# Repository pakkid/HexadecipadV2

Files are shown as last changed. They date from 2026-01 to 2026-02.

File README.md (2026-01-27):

# HexadecipadV2

A fully customizable macro pad with 24 mechanical switches and 4 rotary encoders, designed with KiCAD and featuring an little baby RP2040 microcontroller.

## Overview

HexadecipadV2 is hackpad designed for the blueprint/hackpad ysws. I spent about 6 hours pulling my hair out over case design before I knew what I was doing... ps. I still have no idea what I'm doing.

**Key Features:**
- 24 hot-swap MX-compatible mechanical switches (oops)
- 4 rotary encoders for volume control, scrolling, or custom functions (more oops)
- Seeed Studio XIAO RP2040 microcontroller
- MCP23017 I/O expander because XIAO RP2040 is little baby.
- Open-source KiCAD design because i broke.
- 3D-printed case 👍
- Too many inputs. checked with Blueprint Support, they said its fine as long as I pay.
- Too big pcb (100mmx130mm) also checked with Blueprint staff.
- Fully custom vibe coded garbage script that send serial to a python script on my pc so we can modify keys without having to use stupid kmk.

## Project Structure (just the READMEs for when you access on github.io)

```
HexadecipadV2/
├── CAD/                     # Case and mechanical design files
│   └── README.md            # CAD file documentation
├── Firmware/                # Source firmware code
│   └── README.md            # Firmware documentation
├── PCB/                     # KiCad PCB design files
│   └── HexadecipadV2/       # Main PCB project
│       └── README.md        # PCB documentation
├── Production/              # Manufacturing-ready files
│   ├── CAD/                 # STL files for 3D printing
│   │   └── README.md        # 3D printing guide
│   ├── Firmware/            # Production firmware
│   │   └── README.md        # Firmware installation guide
│   ├── PCB/                 # Gerber files for PCB fab
│   │   └── README.md        # PCB ordering guide
│   └── README.md            # Production overview
└── Other files/             # Supporting files
    ├── 3d models/           # Component STEP models
    │   └── README.md        # 3D models documentation
    ├── images/              # Documentation images
    │   └── README.md        # Images documentation
    └── README.md            # Other files overview
```

### Links and stuff
- **[CAD Files](CAD/)** - Case design and mechanical files
- **[Firmware](Firmware/)** - Source code and development files
- **[PCB Design](PCB/)** - KiCad project and design files
- **[Production Files](Production/)** - Ready-to-manufacture files
  - [3D Printable Case Files](Production/CAD/)
  - [Production Firmware](Production/Firmware/)
  - [PCB Manufacturing Files](Production/PCB/)
- **[Other Files](Other%20files/)** - Component models and documentation images
 
## Screenshots

### Hackpad

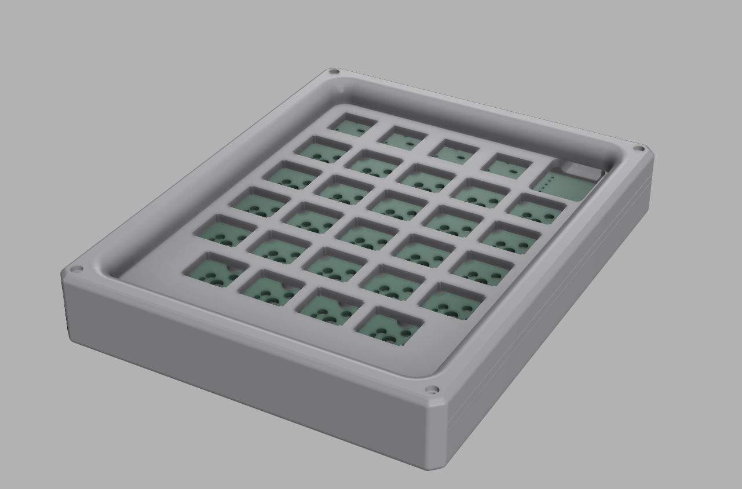
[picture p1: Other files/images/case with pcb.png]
Hackpad Overview


### Schematic

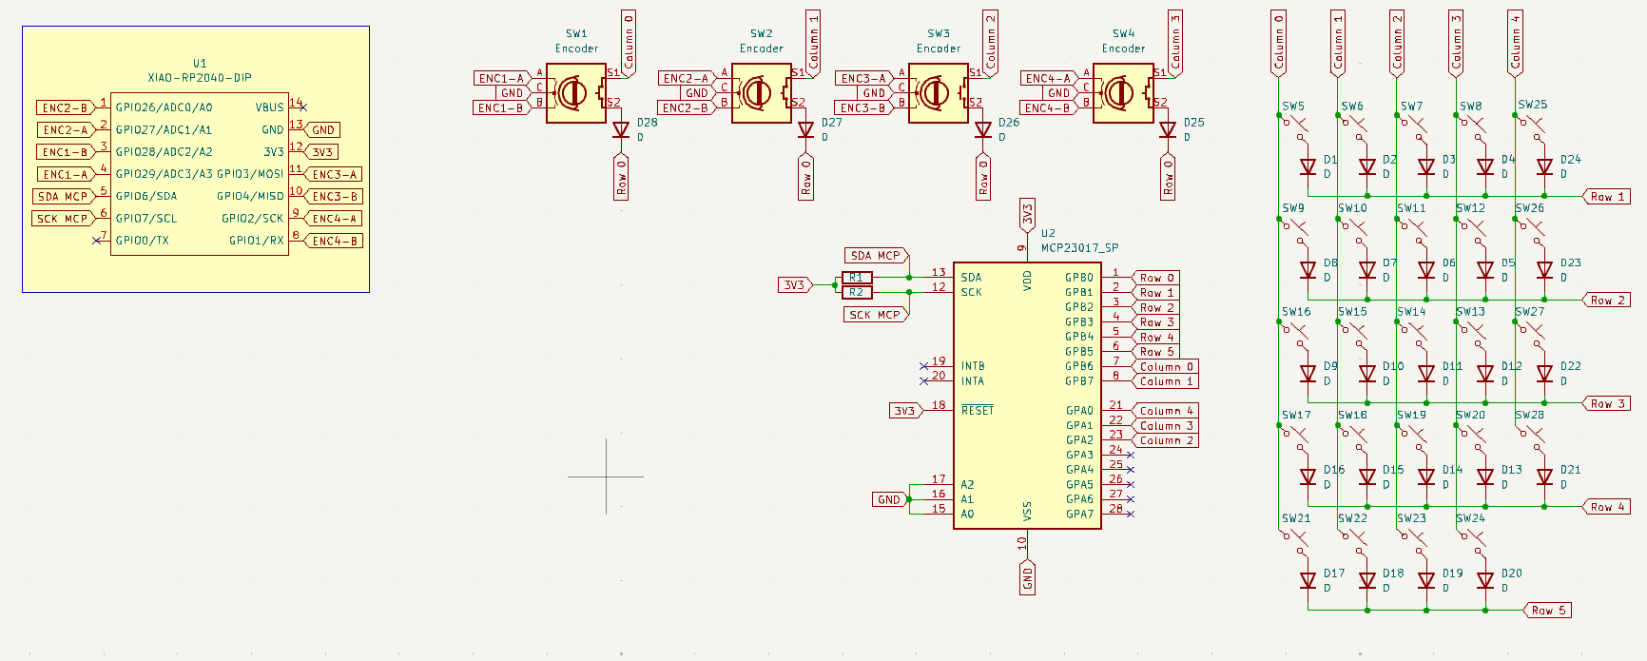
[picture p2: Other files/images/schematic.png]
Schematic


### PCB

**PCB Filled:**
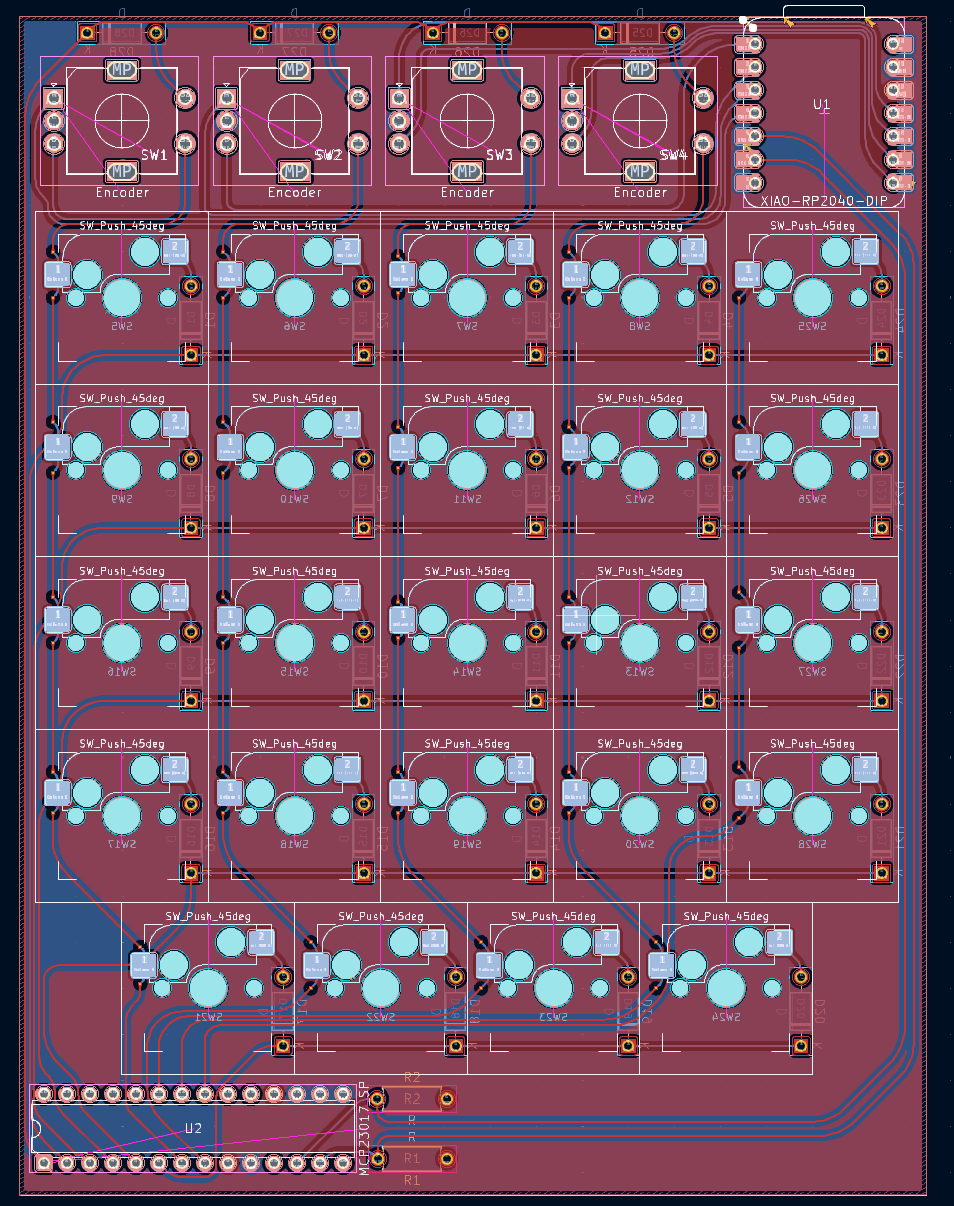
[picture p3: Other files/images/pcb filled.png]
PCB Filled


**PCB Unfilled:**
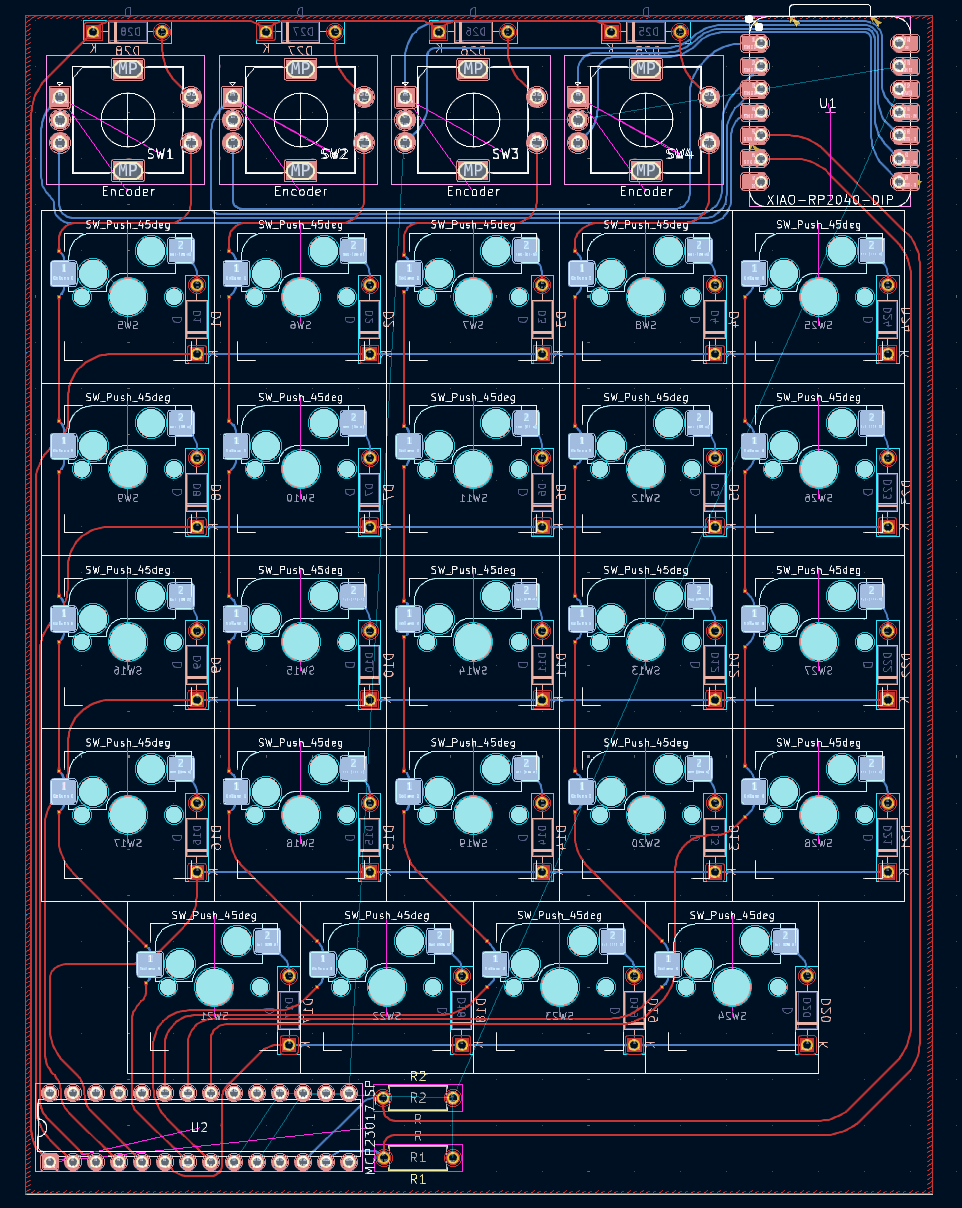
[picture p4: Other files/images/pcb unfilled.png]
PCB Unfilled


### Case Assembly

Case Assembly

## Bill of Materials (BOM)

| # | References | Value | Footprint | Quantity |
|---|---|---|---|---|
| 1 | R1, R2 | R | R_Axial_DIN0207_L6.3mm_D2.5mm_P7.62mm_Horizontal | 2 |
| 2 | D1–D28 | D | D_DO-35_SOD27_P7.62mm_Horizontal | 28 |
| 3 | U1 | XIAO-RP2040-DIP | XIAO-RP2040-DIP | 1 |
| 4 | U2 | MCP23017_SP | DIP-28_W7.62mm | 1 |
| 5 | SW5–SW28 | SW_Push_45deg | MX-Hotswap-1U | 24 |
| 6 | SW1–SW4 | Encoder | RotaryEncoder_Alps_EC11E-Switch_Vertical_H20mm | 4 |
| 7 | N/A | M3x16mm screws | N/A | 4 |

 - **[Interactive BOM](https://hxdcpd.stuffandthings.cc/PCB/HexadecipadV2/bom/ibom.html)**

## Design Files

- **Schematic:** [PCB/HexadecipadV2/HexadecipadV2.kicad_sch](PCB/HexadecipadV2/HexadecipadV2.kicad_sch)
- **PCB Layout:** [PCB/HexadecipadV2/HexadecipadV2.kicad_pcb](PCB/HexadecipadV2/HexadecipadV2.kicad_pcb)
- **PCB 3D Model:** [PCB/HexadecipadV2/HexadecipadV2.step](PCB/HexadecipadV2/HexadecipadV2.step)
- **Case Design:** [CAD/HexadecipadV2-assembled.step](CAD/HexadecipadV2-assembled.step)

### Firmware

Have a look at [Firmware](Firmware/) to see my stupid code.

## License

This project is licensed under the MIT License - see the [LICENSE](LICENSE) file for details.

## Contributing

Contributing will probably end up with me being fried because of my terrible everything in this project.

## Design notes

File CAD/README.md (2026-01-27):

# CAD Directory

This directory contains all Computer-Aided Design (CAD) files for the HexadecipadV2 case and mechanical design.

## Files

### Case Design Files

- **Case-Production.shapr** - Shapr3D native file format for the case design (editable source file)
- **Case.step** - STEP format export of the case design for universal CAD compatibility
- **Case.x_t** - Parasolid format export of the case design
- **HexadecipadV2-assembled.step** - Complete assembled model in STEP format showing the full device assembly
- **platecutout.dxf** - DXF file for the switch plate cutout pattern, used for laser cutting or CNC machining

## File Formats

- `.shapr` - Shapr3D native format (requires Shapr3D software)
- `.step` / `.stp` - Industry-standard 3D CAD format, compatible with most CAD software
- `.x_t` - Parasolid format, widely supported in professional CAD applications
- `.dxf` - 2D drawing exchange format for manufacturing processes

## Usage

The production-ready files for manufacturing are:
- `platecutout.dxf` for the switch plate
- `Case.step` or `Case.x_t` for the case (depending on your manufacturer's preference)

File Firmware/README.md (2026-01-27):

# Firmware Directory

This directory contains the source firmware code for the HexadecipadV2.

## Files

- **main.py** - Main entry point for the CircuitPython firmware
- **hexadecipad_control.py** - Control logic and functionality for the Hexadecipad (key handling, LED control, etc.)

## Hardware Requirements

This firmware is designed for:
- Seeed Studio XIAO RP2040 microcontroller
- CircuitPython 10.0.3 or compatible version

For production-ready firmware files, see the `/Production/Firmware/` directory.

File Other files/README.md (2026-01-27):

# Other Files Directory

This directory contains supporting files including 3D models and documentation images.

## Subdirectories

### 3d models/
Contains 3D STEP models of components used in the design:
- **asm_mx_asm_PCB.stp** - MX mechanical switch assembly with PCB
- **Encoder.STEP** - Rotary encoder 3D model
- **Seeed Studio XIAO RP2040 v26.step** - 3D model of the XIAO RP2040 microcontroller

### images/
Contains project documentation images:
- **case with pcb.png** - Render showing the PCB mounted in the case
- **pcb filled.png** - PCB view with filled copper zones visible
- **pcb unfilled.png** - PCB view without filled zones
- **schematic.png** - Electronic schematic diagram

## Usage

These files are primarily used for:
- 3D models: CAD visualization and mechanical clearance verification
- Images: README documentation and project showcase

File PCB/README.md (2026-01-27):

# PCB Directory

This directory contains the printed circuit board (PCB) design files for HexadecipadV2.

## Subdirectories

### HexadecipadV2/
Main PCB design directory containing all KiCad project files:

#### Project Files
- **HexadecipadV2.kicad_pro** - KiCad project file
- **HexadecipadV2.kicad_sch** - KiCad schematic file
- **HexadecipadV2.kicad_pcb** - KiCad PCB layout file
- **HexadecipadV2.kicad_prl** - KiCad project local settings
- **HexadecipadV2.step** - 3D model export of the PCB

#### Configuration Files
- **fp-lib-table** - Footprint library table
- **sym-lib-table** - Symbol library table
- **fp-info-cache** - Footprint information cache

#### Subdirectories
- **3d models/** - Component 3D models for PCB visualization
- **bom/** - Bill of Materials files (includes `ibom.html` - Interactive HTML BOM)
- **libraries/** - Custom KiCad libraries including footprints and symbols
  - `Hackpad/` - Custom Hackpad symbols and footprints
  - `kicad-keyboard-parts.pretty-master/` - Keyboard-specific footprints
  - `MX_V2-main/` - MX switch footprint library
  - `OPL_Kicad_Library-master/` - Open Parts Library
  - `RotaryEncoder/` - Rotary encoder components
- **HexadecipadV2-backups/** - Automatic KiCad backup files

## Software Requirements

- KiCad 7.0 or later (recommended for full compatibility)

## Usage

1. Open `HexadecipadV2.kicad_pro` in KiCad to view and edit the design
2. Use `ibom.html` in the `bom/` folder for assembly reference
3. For manufacturing files, see the `/Production/PCB/` directory

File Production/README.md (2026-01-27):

# Production Directory

This directory contains production-ready files for manufacturing and assembly of the HexadecipadV2.

## Subdirectories

### CAD/
3D printable STL files for case manufacturing:
- **Case bottom.stl** - Bottom half of the case
- **Case top.stl** - Top half of the case
- **Plate.stl** - Switch mounting plate

### Firmware/
Production firmware ready for deployment:
- **adafruit-circuitpython-seeeduino_xiao_rp2040-en_US-10.0.3.uf2** - CircuitPython bootloader/runtime for XIAO RP2040
- **CIRCUITPY/** - Directory structure to be copied to the device
  - `main.py` - Production firmware main file
  - `lib/` - Required CircuitPython libraries

### PCB/
Manufacturing files for PCB fabrication:
- **Hexadecipad_V2_TDSOTM_Edition.zip** - Complete Gerber files and manufacturing package for PCB production
- **netlist.ipc** - IPC-356 netlist for PCB testing and verification

## Manufacturing Instructions

### PCB
1. Send `Hexadecipad_V2_TDSOTM_Edition.zip` to your PCB manufacturer
2. Recommended specs: Check the PCB.md file in /PCB/HexadecipadV2/

### Case
1. 3D print the STL files in the CAD/ directory
2. Recommended settings: 0.2mm layer height, 20% infill or higher
3. Material: PLA, ABS, or really whatever you want

### Firmware Installation
1. Flash `adafruit-circuitpython-seeeduino_xiao_rp2040-en_US-10.0.3.uf2` to the XIAO RP2040 by entering bootloader mode
2. Copy contents of `CIRCUITPY/` to the mounted CIRCUITPY drive
3. Device will automatically restart with the firmware

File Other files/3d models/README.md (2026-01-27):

# 3D Models

This directory contains STEP files of electronic components used in the HexadecipadV2 design.

## Files

- **asm_mx_asm_PCB.stp** - Complete assembly model of MX mechanical keyboard switch with PCB mounting
- **Encoder.STEP** - 3D model of the rotary encoder component
- **Seeed Studio XIAO RP2040 v26.step** - 3D model of the Seeed Studio XIAO RP2040 microcontroller board (version 26)

## Usage

These STEP models are used for:
- Verifying mechanical clearances in CAD assemblies
- Creating accurate renders and visualizations
- Checking component fit and interference
- PCB 3D visualization in KiCad

These files can be imported into most CAD software packages including KiCad, Fusion 360, SolidWorks, and FreeCAD.

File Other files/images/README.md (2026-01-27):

# Images

This directory contains documentation and visualization images for the HexadecipadV2 project.

## Files

- **case with pcb.png** - 3D render showing the PCB installed in the case assembly
- **pcb filled.png** - PCB layout view with filled copper zones (ground and power planes visible)
- **pcb unfilled.png** - PCB layout view with unfilled zones (traces and routing more visible)
- **schematic.png** - Complete electronic schematic diagram of the circuit

## Usage

These images are used in:
- Project README and documentation
- Assembly guides
- Design reviews
- Showcasing the project

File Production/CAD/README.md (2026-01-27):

# Production CAD Files

This directory contains production-ready STL files for 3D printing the HexadecipadV2 case.

## Files

- **Case bottom.stl** - Bottom housing of the case
- **Case top.stl** - Top housing/cover of the case
- **Plate.stl** - Switch mounting plate (goes between top and bottom)

## 3D Printing Recommendations

### Settings
- **Layer Height:** 0.2mm (or 0.15mm for better surface finish)
- **Infill:** 20% or higher
- **Wall Thickness:** 3-4 perimeters
- **Top/Bottom Layers:** 4-5 layers

### Print Orientation
Orient parts to minimize supports and maximize strength. The plate should be printed flat for dimensional accuracy.

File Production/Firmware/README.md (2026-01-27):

# Production Firmware

This directory contains production-ready firmware files for the HexadecipadV2.

## Files

- **adafruit-circuitpython-seeeduino_xiao_rp2040-en_US-10.0.3.uf2** - CircuitPython 10.0.3 firmware for the Seeed Studio XIAO RP2040

### CIRCUITPY/
Directory structure to be copied to the device after CircuitPython installation:
- **main.py** - Main firmware application
- **lib/** - Required CircuitPython libraries and dependencies

## Installation Instructions

### Step 1: Install CircuitPython Bootloader
1. Connect your XIAO RP2040 to your computer via USB
2. Press the RESET button twice quickly to enter bootloader mode
3. A drive named "RPI-RP2" should appear
4. Copy `adafruit-circuitpython-seeeduino_xiao_rp2040-en_US-10.0.3.uf2` to the RPI-RP2 drive
5. The device will automatically reboot and appear as "CIRCUITPY"

### Step 2: Install Firmware
1. Copy the entire contents of the `CIRCUITPY/` folder to the CIRCUITPY drive
2. Ensure `main.py` is in the root of the CIRCUITPY drive
3. Copy the `lib/` folder and its contents to the CIRCUITPY drive
4. The device will automatically restart and run the firmware

## Troubleshooting

- If the device doesn't appear as CIRCUITPY after step 1, try pressing RESET twice again
- If there are errors, check the `serial console` for error messages
- Ensure all required libraries are present in the `lib/` folder

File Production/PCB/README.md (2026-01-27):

# Production PCB Files

This directory contains manufacturing files for PCB fabrication.

## Files

- **Hexadecipad_V2_TDSOTM_Edition.zip** - Gerbers and drill files

- **netlist.ipc** - IPC-356 netlist file for electrical testing and verification of the manufactured PCB

## Ordering PCBs

### Upload Files
1. Upload `Hexadecipad_V2_TDSOTM_Edition.zip` to your PCB manufacturer (JLCPCB, PCBWay, OSH Park, etc.)

### Recommended Specifications
- Check the main PCB.md file in `/PCB/HexadecipadV2/` for detailed specifications
- Common settings:
  - **Layers:** 2
  - **PCB Thickness:** 1.6mm (standard)
  - **Surface Finish:** HASL or ENIG
  - **Copper Weight:** 1oz (35μm)

### Assembly
- For hand assembly, use the interactive BOM in `/PCB/HexadecipadV2/bom/ibom.html`
- For automated assembly, the pick-and-place files are included in the ZIP

## Quality Control

The `netlist.ipc` file can be used by the manufacturer or for in-house testing to verify:
- All connections are correct
- No short circuits exist
- All nets are properly connected

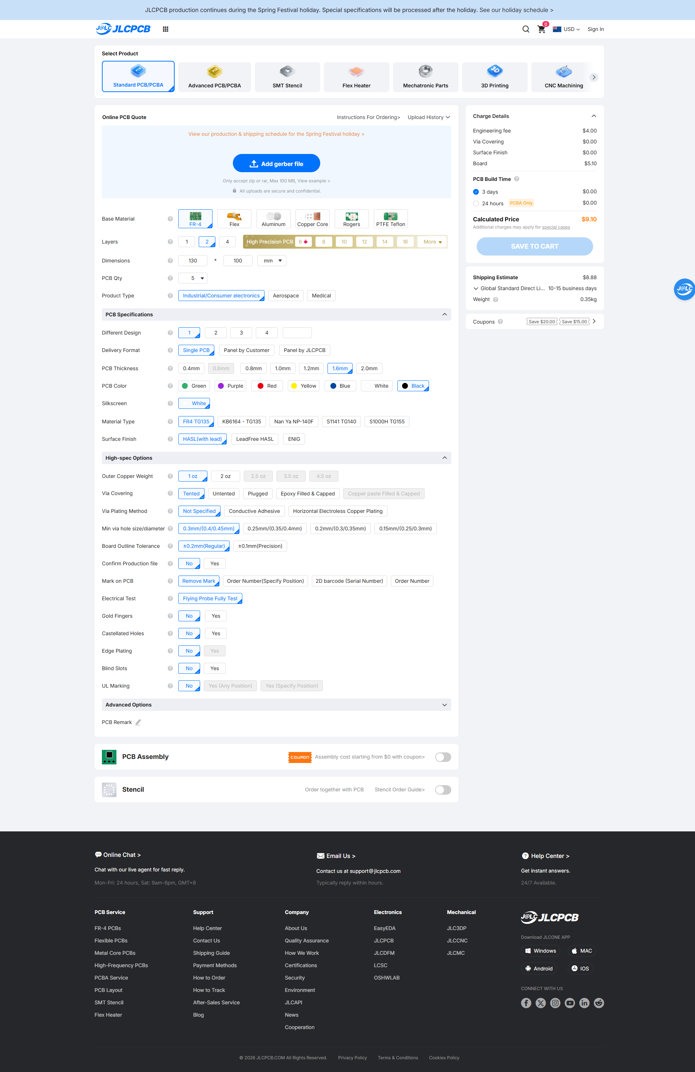
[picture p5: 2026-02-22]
PCB/screenshots-jlcpcb/130x100.png

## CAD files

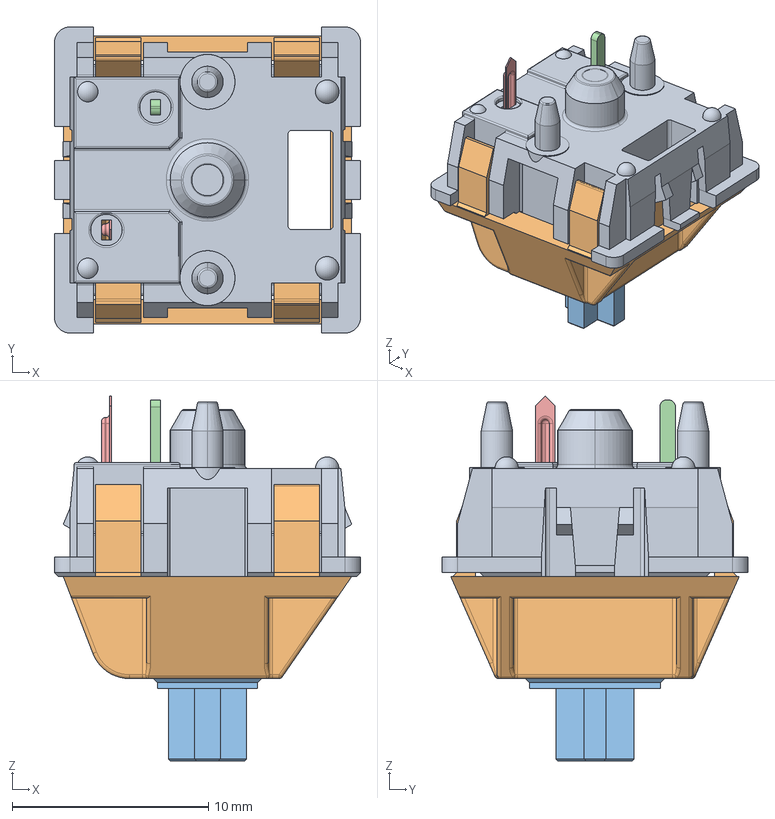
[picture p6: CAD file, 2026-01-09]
Other files/3d models/asm_mx_asm_PCB.stp
15.6 x 15.6 x 18.6 mm
MX_DOWN
MX_UP
UP_MX
MX_PIN
MX_SPRING
MX_CLICK

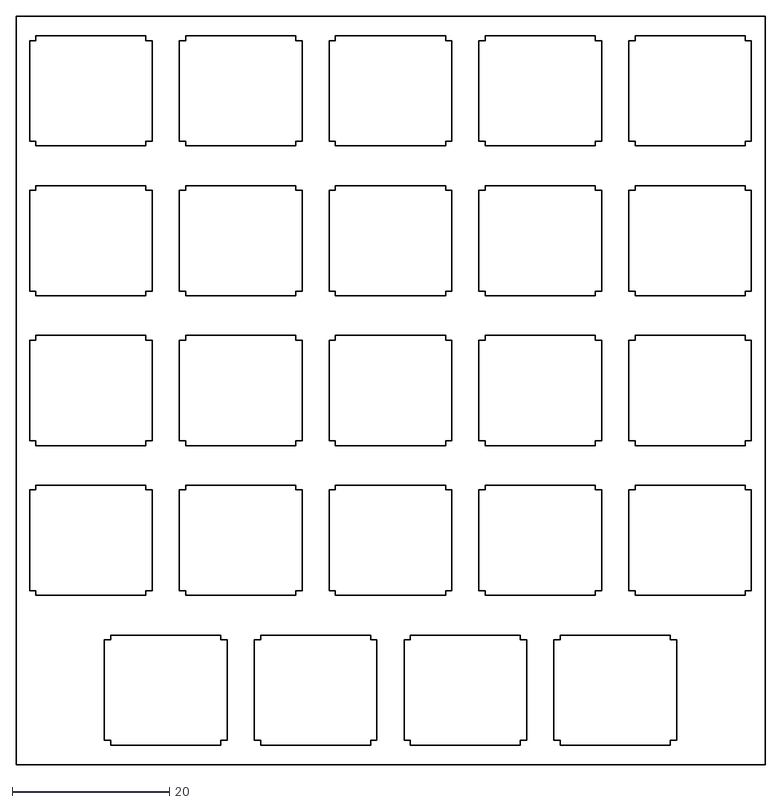
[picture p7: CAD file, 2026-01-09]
CAD/platecutout.dxf
95.3 x 95.2

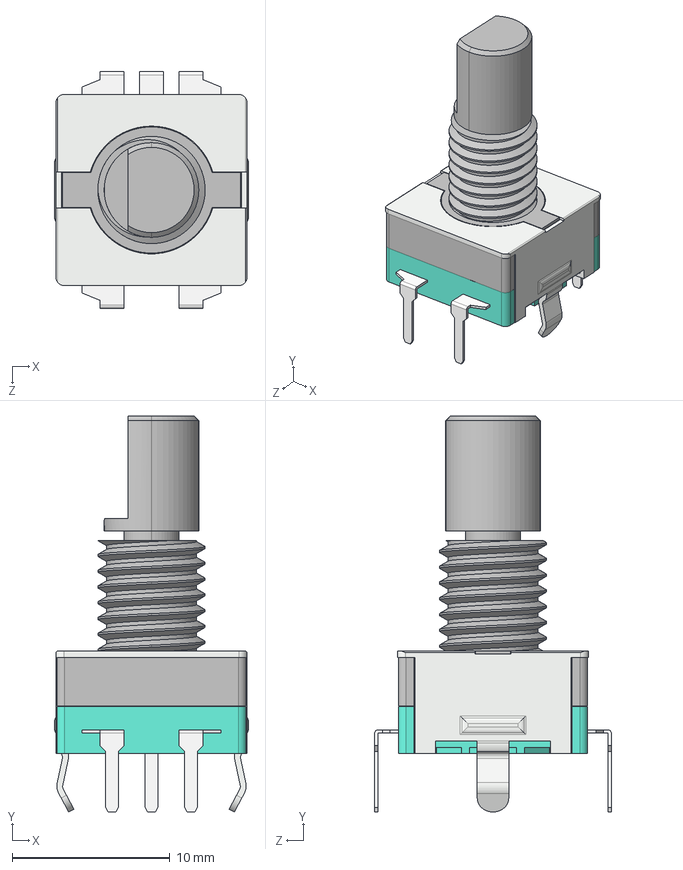
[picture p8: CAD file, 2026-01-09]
Other files/3d models/Encoder.STEP
12.3 x 25.1 x 15.0 mm

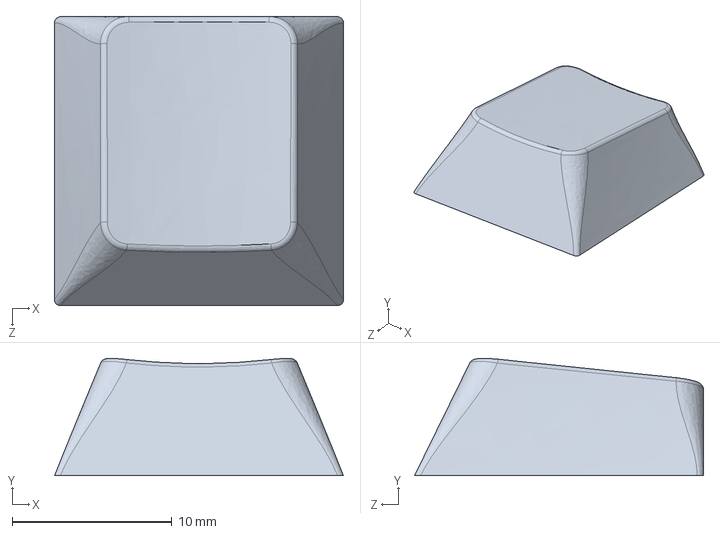
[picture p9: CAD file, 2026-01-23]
PCB/HexadecipadV2/3d models/r3_100.STEP
18.1 x 7.34 x 18.1 mm

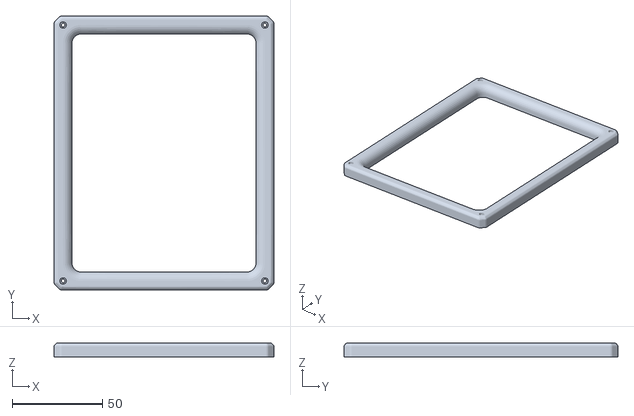
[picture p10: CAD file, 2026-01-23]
Production/CAD/Case top.stl
122.0 x 152.0 x 8.00

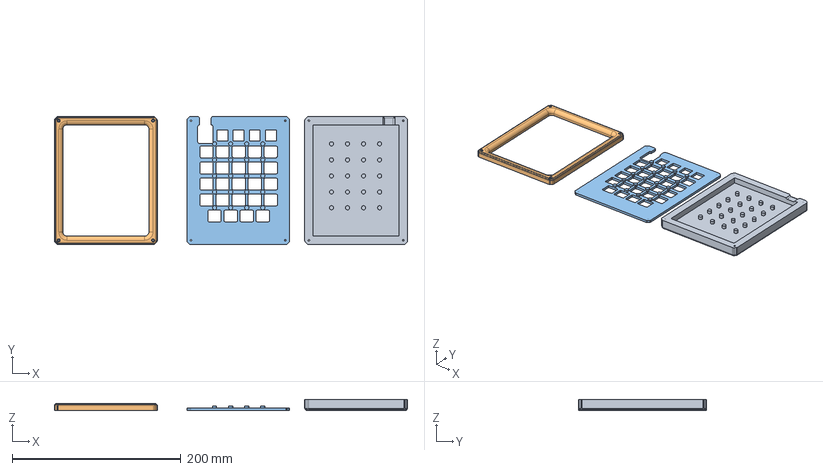
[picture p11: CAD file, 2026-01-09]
CAD/Case.step
419.0 x 152.0 x 12.6 mm
MX_DOWN
MX_UP
UP_MX
MX_PIN
MX_SPRING
MX_CLICK
type-c v2:1
smd_button v3:1
DOUT:1
DIN:1
VSS:1
VDD:1
smd_button v3(Mirror):1
Encoder x 4
DIP-28_W7.62mm
R_Axial_DIN0207_L6.3mm_D2.5mm_P7.62mm_Horizontal x 2
MX-Hotswap-Socket x 24
D_DO-35_SOD27_P7.62mm_Horizontal x 28
HexadecipadV2_silkscreen
HexadecipadV2_PCB
temp_import

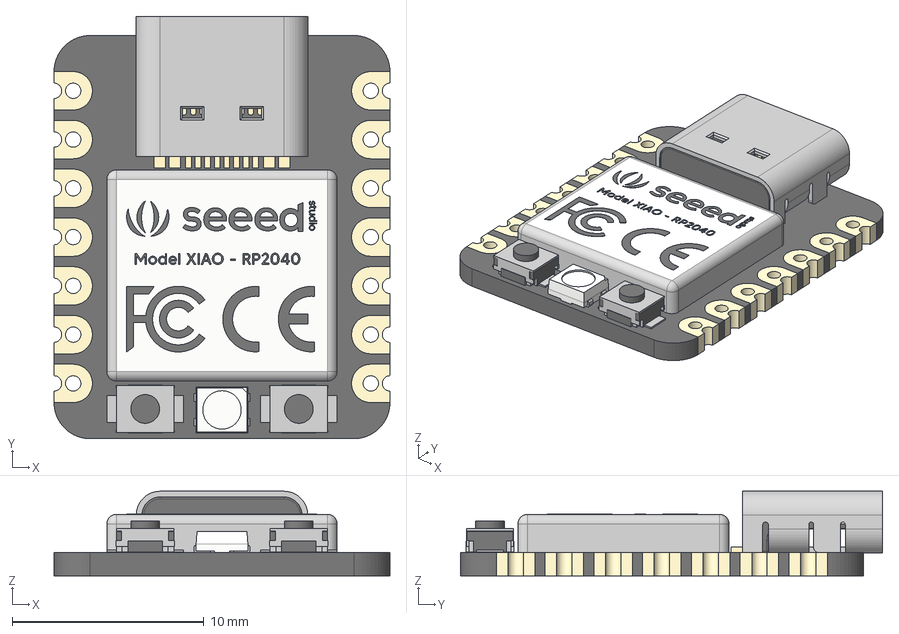
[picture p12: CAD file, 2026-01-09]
Other files/3d models/Seeed Studio XIAO RP2040 v26.step
17.5 x 22.0 x 4.40 mm
type-c v2
smd_button v3
DOUT
DIN
VSS
VDD
smd_button v3(Mirror)

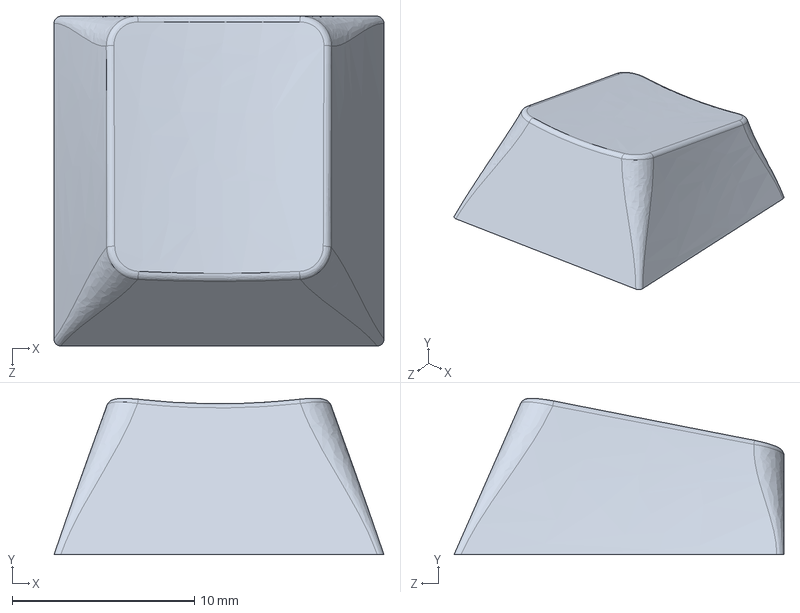
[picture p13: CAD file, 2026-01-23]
PCB/HexadecipadV2/3d models/r4_100.STEP
18.1 x 8.58 x 18.1 mm

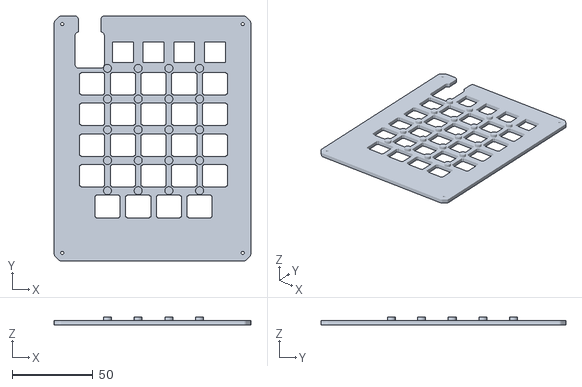
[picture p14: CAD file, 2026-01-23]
Production/CAD/Plate.stl
122.0 x 152.0 x 5.10

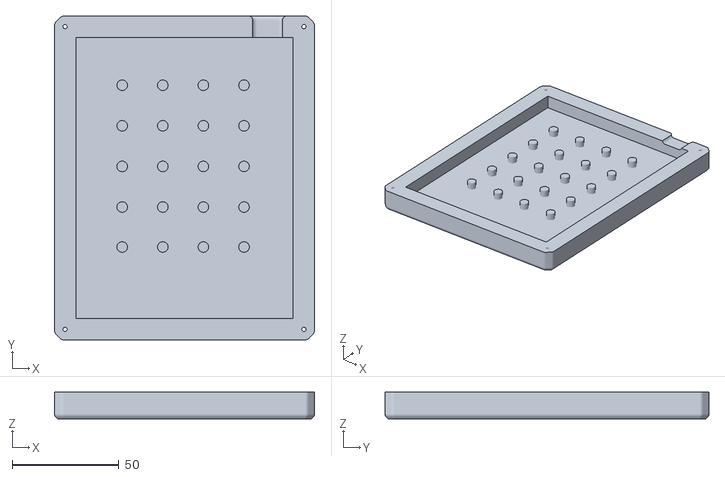
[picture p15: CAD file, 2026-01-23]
Production/CAD/Case bottom.stl
122.0 x 152.0 x 12.6

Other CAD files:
CAD/Case.x_t

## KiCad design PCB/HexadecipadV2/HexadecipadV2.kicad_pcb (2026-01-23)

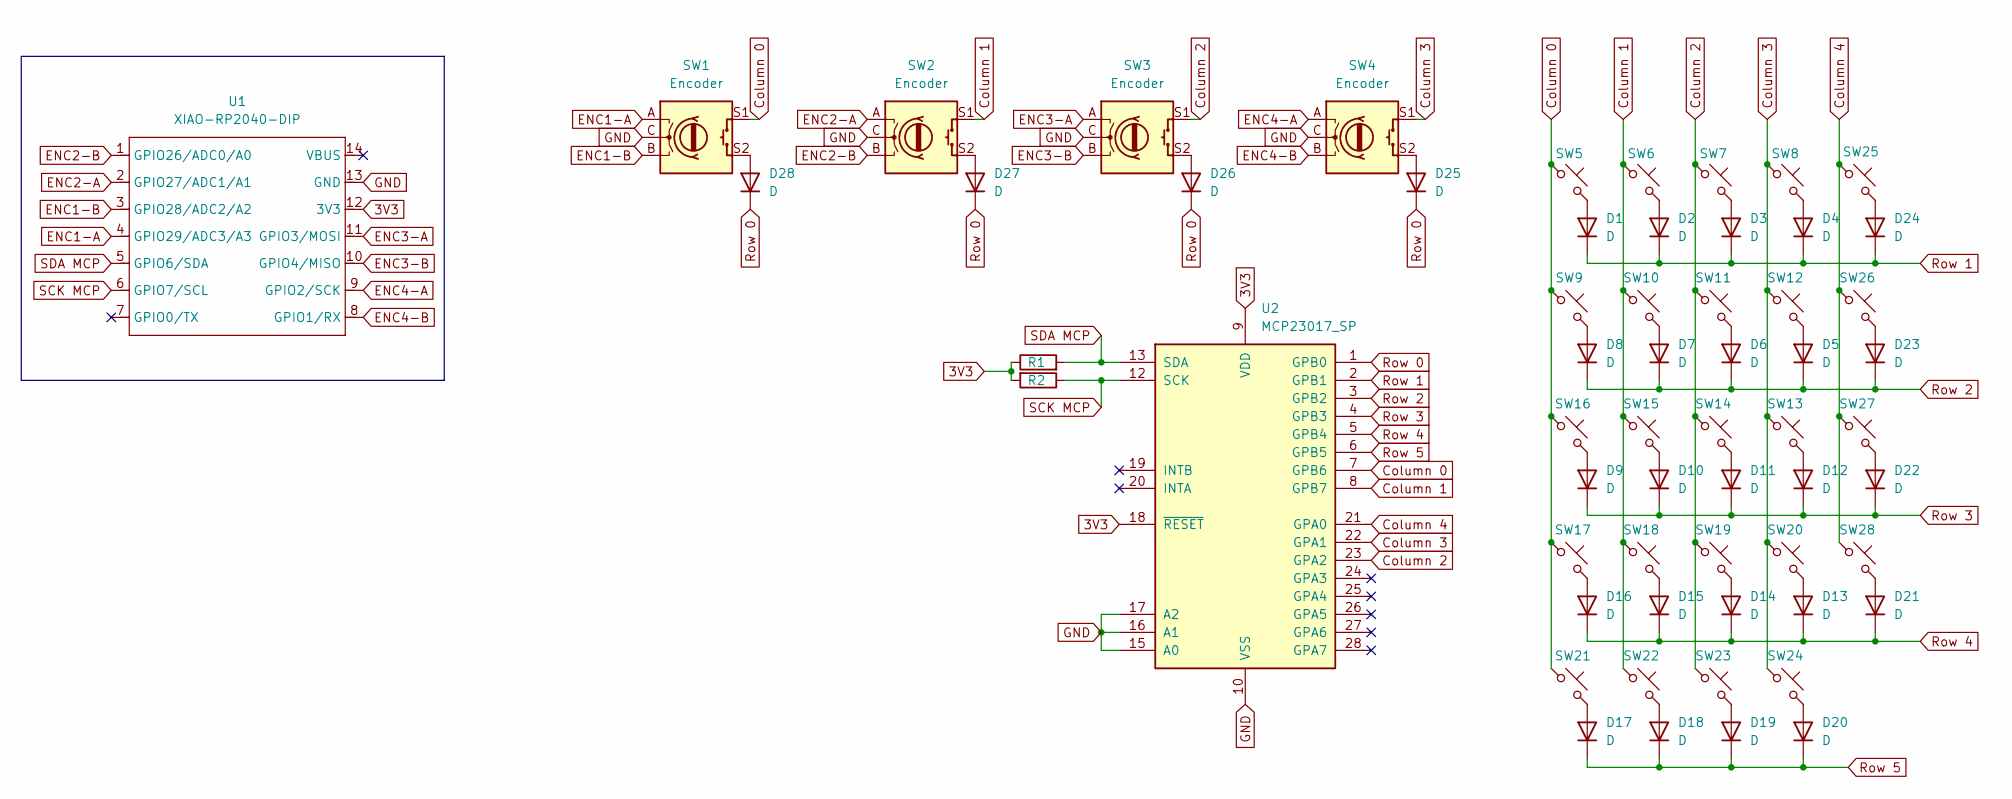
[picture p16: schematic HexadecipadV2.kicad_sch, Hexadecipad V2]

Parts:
D1, D2, D3, D4, D5, D6, D7, D8, D9, D10, D11, D12, D13, D14, D15, D16, D17, D18, D19, D20, D21, D22, D23, D24, D25, D26, D27, D28: D; D_DO-35_SOD27_P7.62mm_Horizontal
R1, R2: R; R_Axial_DIN0207_L6.3mm_D2.5mm_P7.62mm_Horizontal
SW1, SW2, SW3, SW4: Encoder; RotaryEncoder_Alps_EC11E-Switch_Vertical_H20mm
SW5, SW6, SW7, SW8, SW9, SW10, SW11, SW12, SW13, SW14, SW15, SW16, SW17, SW18, SW19, SW20, SW21, SW22, SW23, SW24, SW25, SW26, SW27, SW28: SW_Push_45deg; MX-Hotswap-1U
U1: XIAO-RP2040-DIP
U2: MCP23017_SP; DIP-28_W7.62mm

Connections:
3V3: R1.1, R2.2, U1.12 (3V3), U2.9 (VDD), U2.18 (~RESET)
Column 0: SW1.S1, SW5.1, SW9.1, SW16.1, SW17.1, SW21.1, U2.7 (GPB6)
Column 1: SW2.S1, SW6.1, SW10.1, SW15.1, SW18.1, SW22.1, U2.8 (GPB7)
Column 2: SW3.S1, SW7.1, SW11.1, SW14.1, SW19.1, SW23.1, U2.23 (GPA2)
Column 3: SW4.S1, SW8.1, SW12.1, SW13.1, SW20.1, SW24.1, U2.22 (GPA1)
Column 4: SW25.1, SW26.1, SW27.1, SW28.1, U2.21 (GPA0)
ENC1-A: SW1.A, U1.4 (GPIO29/ADC3/A3)
ENC1-B: SW1.B, U1.3 (GPIO28/ADC2/A2)
ENC2-A: SW2.A, U1.2 (GPIO27/ADC1/A1)
ENC2-B: SW2.B, U1.1 (GPIO26/ADC0/A0)
ENC3-A: SW3.A, U1.11 (GPIO3/MOSI)
ENC3-B: SW3.B, U1.10 (GPIO4/MISO)
ENC4-A: SW4.A, U1.9 (GPIO2/SCK)
ENC4-B: SW4.B, U1.8 (GPIO1/RX)
GND: SW1.C, SW2.C, SW3.C, SW4.C, U1.13 (GND), U2.10 (VSS), U2.15 (A0), U2.16 (A1), U2.17 (A2)
unnamed: D1.2 (A), SW5.2
unnamed: D2.2 (A), SW6.2
unnamed: D3.2 (A), SW7.2
unnamed: D4.2 (A), SW8.2
unnamed: D5.2 (A), SW12.2
unnamed: D6.2 (A), SW11.2
unnamed: D7.2 (A), SW10.2
unnamed: D8.2 (A), SW9.2
unnamed: D9.2 (A), SW16.2
unnamed: D10.2 (A), SW15.2
unnamed: D11.2 (A), SW14.2
unnamed: D12.2 (A), SW13.2
unnamed: D13.2 (A), SW20.2
unnamed: D14.2 (A), SW19.2
unnamed: D15.2 (A), SW18.2
unnamed: D16.2 (A), SW17.2
unnamed: D17.2 (A), SW21.2
unnamed: D18.2 (A), SW22.2
unnamed: D19.2 (A), SW23.2
unnamed: D20.2 (A), SW24.2
unnamed: D21.2 (A), SW28.2
unnamed: D22.2 (A), SW27.2
unnamed: D23.2 (A), SW26.2
unnamed: D24.2 (A), SW25.2
unnamed: D25.2 (A), SW4.S2
unnamed: D26.2 (A), SW3.S2
unnamed: D27.2 (A), SW2.S2
unnamed: D28.2 (A), SW1.S2
Row 0: D25.1 (K), D26.1 (K), D27.1 (K), D28.1 (K), U2.1 (GPB0)
Row 1: D1.1 (K), D2.1 (K), D3.1 (K), D4.1 (K), D24.1 (K), U2.2 (GPB1)
Row 2: D5.1 (K), D6.1 (K), D7.1 (K), D8.1 (K), D23.1 (K), U2.3 (GPB2)
Row 3: D9.1 (K), D10.1 (K), D11.1 (K), D12.1 (K), D22.1 (K), U2.4 (GPB3)
Row 4: D13.1 (K), D14.1 (K), D15.1 (K), D16.1 (K), D21.1 (K), U2.5 (GPB4)
Row 5: D17.1 (K), D18.1 (K), D19.1 (K), D20.1 (K), U2.6 (GPB5)
SCK MCP: R2.1, U1.6 (GPIO7/SCL), U2.12 (SCK)
SDA MCP: R1.2, U1.5 (GPIO6/SDA), U2.13 (SDA)

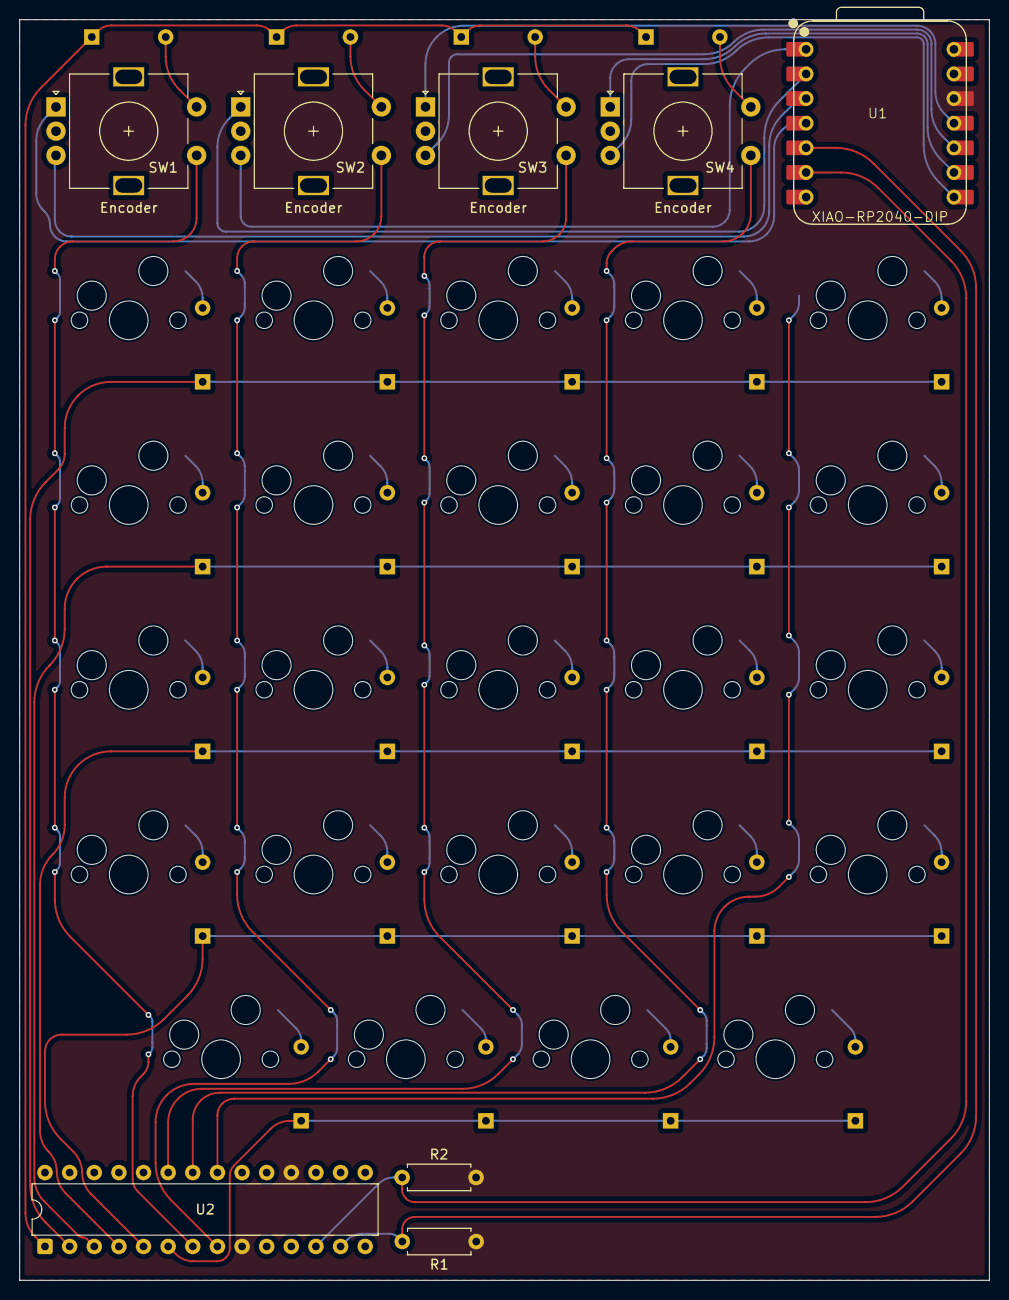
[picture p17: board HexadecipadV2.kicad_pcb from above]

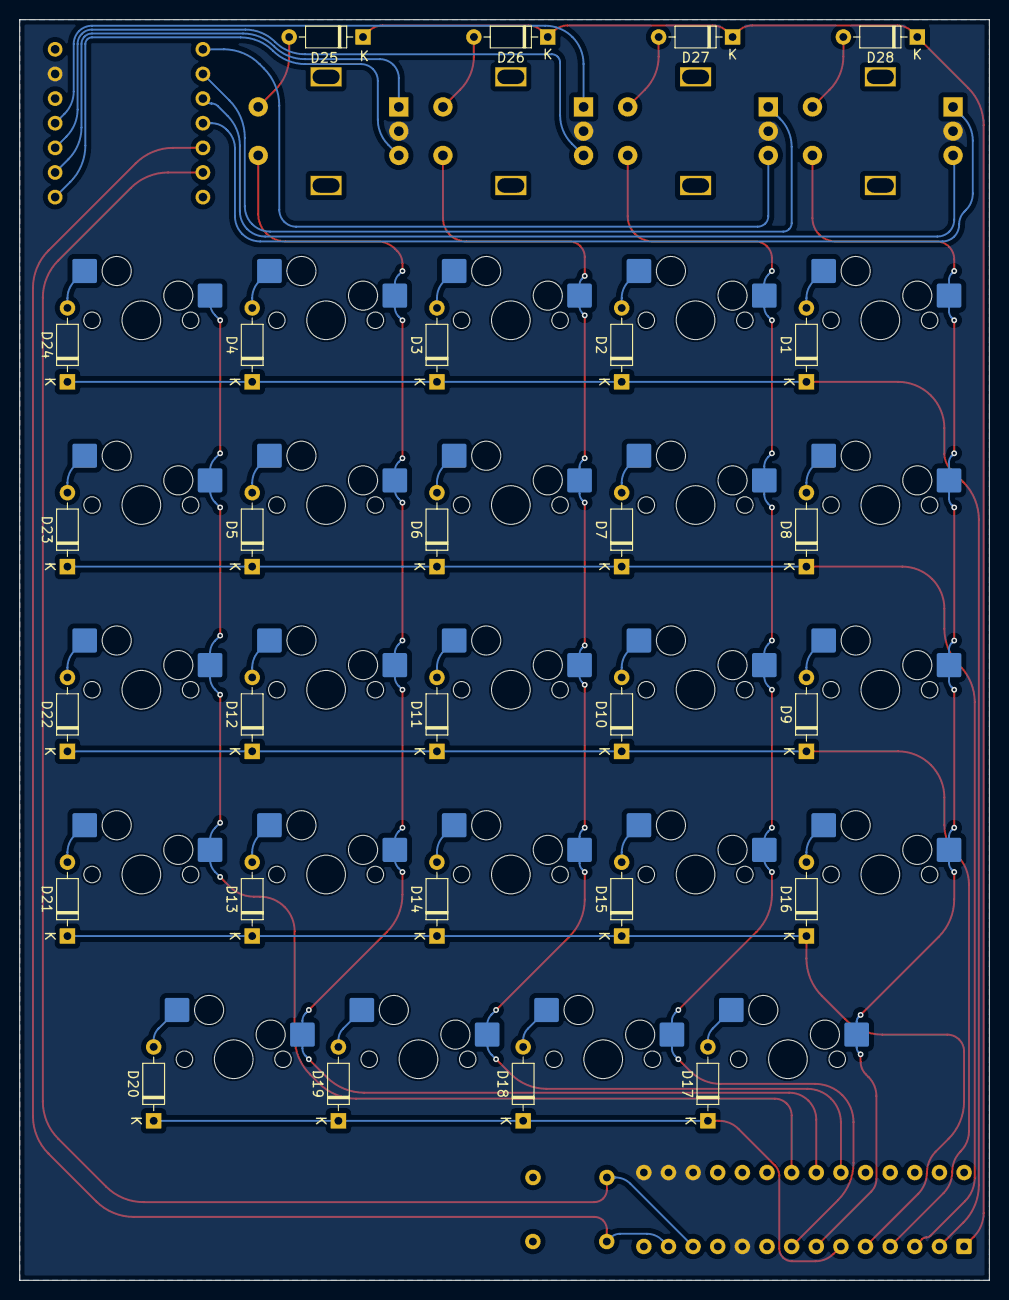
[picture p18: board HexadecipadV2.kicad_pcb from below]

Board: 2 copper layers, 100.0 x 130.0 mm, 60 parts (52 on the bottom side), 51 nets.

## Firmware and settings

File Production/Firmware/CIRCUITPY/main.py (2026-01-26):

"""
Hexadecipad V2 Firmware
Pure CircuitPython - reads matrix and encoders, sends data over USB serial
No keyboard framework needed - just raw I/O and protocol
"""

import board
import busio
import time
from adafruit_mcp230xx.mcp23017 import MCP23017
import usb_cdc

# I2C configuration - SDA on GPIO6 (D4), SCL on GPIO7 (D5)
i2c = busio.I2C(board.D5, board.D4)  # D5=SCL (GPIO7), D4=SDA (GPIO6)
mcp = MCP23017(i2c, address=0x20)    # A0, A1, A2 all grounded = 0x20

console = usb_cdc.console

def send_message(message):
    """Send message over USB serial"""
    try:
        console.write(message + "\n")
    except:
        pass

# ============================================================================
# MCP23017 PIN CONFIGURATION
# ============================================================================

# GPIOA pins (0-7)
GPA0 = mcp.get_pin(0)   # Column 4
GPA1 = mcp.get_pin(1)   # Column 3
GPA2 = mcp.get_pin(2)   # Column 2
GPA3 = mcp.get_pin(3)   # Unused
GPA4 = mcp.get_pin(4)   # Unused
GPA5 = mcp.get_pin(5)   # Unused
GPA6 = mcp.get_pin(6)   # Unused
GPA7 = mcp.get_pin(7)   # Unused

# GPIOB pins (8-15)
GPB0 = mcp.get_pin(8)   # Row 0
GPB1 = mcp.get_pin(9)   # Row 1
GPB2 = mcp.get_pin(10)  # Row 2
GPB3 = mcp.get_pin(11)  # Row 3
GPB4 = mcp.get_pin(12)  # Row 4
GPB5 = mcp.get_pin(13)  # Row 5
GPB6 = mcp.get_pin(14)  # Column 0
GPB7 = mcp.get_pin(15)  # Column 1

# Matrix layout
rows = [GPB0, GPB1, GPB2, GPB3, GPB4, GPB5]
cols = [GPB6, GPB7, GPA2, GPA1, GPA0]

# Configure pins as inputs/outputs
# Rows are outputs (driven low to select), Columns are inputs (pulled high)
for row in rows:
    row.switch_to_output(value=True)

for col in cols:
    col.switch_to_input(pull=board.Pull.UP)

# ============================================================================
# ENCODER PINS (RP2040 GPIO)
# ============================================================================

# Xiao RP2040 pin mapping: D0=GPIO26, D1=GPIO27, D2=GPIO28, D3=GPIO29, D7=GPIO1, D8=GPIO2, D9=GPIO4, D10=GPIO3
encoder_pins = [
    (board.D3, board.D2),    # Encoder 1: A=GPIO29/D3, B=GPIO28/D2
    (board.D1, board.D0),    # Encoder 2: A=GPIO27/D1, B=GPIO26/D0
    (board.D10, board.D9),   # Encoder 3: A=GPIO3/D10, B=GPIO4/D9
    (board.D8, board.D7),    # Encoder 4: A=GPIO2/D8, B=GPIO1/D7
]

# Initialize encoder pins as inputs
for pin_a, pin_b in encoder_pins:
    pin_a.switch_to_input()
    pin_b.switch_to_input()

# Track encoder states for detecting rotation
encoder_states = [None] * 4  # Previous state for each encoder
encoder_transitions = {
    # Clockwise transitions (Gray code)
    (0b11, 0b01): 'UP',
    (0b01, 0b00): 'UP',
    (0b00, 0b10): 'UP',
    (0b10, 0b11): 'UP',
    
    # Counter-clockwise transitions
    (0b11, 0b10): 'DOWN',
    (0b10, 0b00): 'DOWN',
    (0b00, 0b01): 'DOWN',
    (0b01, 0b11): 'DOWN',
}

# ============================================================================
# MATRIX SCANNING & KEY TRACKING
# ============================================================================

# Track which keys are currently pressed
key_states = {}  # (row, col) -> is_pressed

# Matrix layout: sparse layout with only certain keys in each row
# Row 0: 4 keys (cols 0-3)
# Row 1-4: 5 keys (cols 0-4)
# Row 5: 4 keys (cols 0-3)
VALID_KEYS = {
    0: [0, 1, 2, 3],           # Row 0: 4 keys
    1: [0, 1, 2, 3, 4],        # Row 1: 5 keys
    2: [0, 1, 2, 3, 4],        # Row 2: 5 keys
    3: [0, 1, 2, 3, 4],        # Row 3: 5 keys
    4: [0, 1, 2, 3, 4],        # Row 4: 5 keys
    5: [0, 1, 2, 3],           # Row 5: 4 keys
}

def scan_matrix():
    """Scan matrix and detect key presses/releases"""
    for row_idx, row_pin in enumerate(rows):
        # Drive this row low, all others high
        for i, r in enumerate(rows):
            r.value = (i != row_idx)
        
        time.sleep(0.001)  # Debounce delay
        
        # Read columns for this row
        for col_idx in VALID_KEYS[row_idx]:
            col_pin = cols[col_idx]
            is_pressed = not col_pin.value  # Column pulled low = key pressed
            
            key_id = (row_idx, col_idx)
            old_state = key_states.get(key_id, False)
            
            if is_pressed != old_state:
                key_states[key_id] = is_pressed
                
                if is_pressed:
                    send_message(f"KEY_R{row_idx}C{col_idx}_PRESSED")
                else:
                    send_message(f"KEY_R{row_idx}C{col_idx}_RELEASED")
        
        # Return all rows to high
        for r in rows:
            r.value = True

def read_encoders():
    """Read encoder rotations"""
    for enc_idx, (pin_a, pin_b) in enumerate(encoder_pins):
        # Read Gray code state: (A << 1) | B
        current_state = (pin_a.value << 1) | pin_b.value
        previous_state = encoder_states[enc_idx]
        
        # Update state
        encoder_states[enc_idx] = current_state
        
        # Detect transitions
        if previous_state is not None:
            transition = (previous_state, current_state)
            if transition in encoder_transitions:
                direction = encoder_transitions[transition]
                send_message(f"ENC{enc_idx+1}_{direction}")

# ============================================================================
# MAIN LOOP
# ============================================================================

# Send startup message
send_message("DEVICE_READY")

# Timing
last_encoder_check = time.monotonic()
encoder_check_interval = 0.005  # Check encoders every 5ms
last_matrix_scan = time.monotonic()
matrix_scan_interval = 0.010     # Scan matrix every 10ms

print("Hexadecipad V2 firmware running...")

while True:
    current_time = time.monotonic()
    
    # Matrix scanning
    if current_time - last_matrix_scan >= matrix_scan_interval:
        scan_matrix()
        last_matrix_scan = current_time
    
    # Encoder reading
    if current_time - last_encoder_check >= encoder_check_interval:
        read_encoders()
        last_encoder_check = current_time
    
    time.sleep(0.001)  # Small delay to prevent spinning

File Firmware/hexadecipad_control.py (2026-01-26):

"""
Hexadecipad V2 Control Application
Listens to custom USB serial protocol from RP2040 and controls audio/apps
Protocol format:
  - KEY_R#C#_PRESSED: Key press (Row/Column)
  - KEY_R#C#_RELEASED: Key release
  - ENC#_UP: Encoder rotation up
  - ENC#_DOWN: Encoder rotation down
  - ENC#_PRESSED: Encoder button press
  - ENC#_RELEASED: Encoder button release
"""

import serial
import serial.tools.list_ports
import time
import os
import subprocess
from pycaw.pycaw import AudioUtilities, ISimpleAudioVolume
from comtypes import CLSCTX_ALL
import threading

class HexadecipadController:
    def __init__(self, port=None, baudrate=115200):
        self.port = port
        self.baudrate = baudrate
        self.ser = None
        self.running = False
        
        # Action configuration - customize these per your needs
        self.action_map = {
            # Encoder 1: Spotify volume
            'ENC1_UP': lambda: self.change_app_volume('spotify', 0.02),
            'ENC1_DOWN': lambda: self.change_app_volume('spotify', -0.02),
            'ENC1_PRESSED': lambda: self.toggle_app_mute('spotify'),
            
            # Encoder 2: Discord volume
            'ENC2_UP': lambda: self.change_app_volume('discord', 0.02),
            'ENC2_DOWN': lambda: self.change_app_volume('discord', -0.02),
            'ENC2_PRESSED': lambda: self.toggle_app_mute('discord'),
            
            # Encoder 3: Game volume
            'ENC3_UP': lambda: self.change_app_volume('game', 0.02),
            'ENC3_DOWN': lambda: self.change_app_volume('game', -0.02),
            'ENC3_PRESSED': lambda: self.toggle_app_mute('game'),
            
            # Encoder 4: Master volume
            'ENC4_UP': lambda: self.change_master_volume(0.02),
            'ENC4_DOWN': lambda: self.change_master_volume(-0.02),
            'ENC4_PRESSED': lambda: self.toggle_master_mute(),
            
            # Customizable key actions
            'KEY_R0C0_PRESSED': lambda: print("Key R0C0 pressed"),
            'KEY_R0C1_PRESSED': lambda: print("Key R0C1 pressed"),
            'KEY_R0C2_PRESSED': lambda: print("Key R0C2 pressed"),
            'KEY_R0C3_PRESSED': lambda: print("Key R0C3 pressed"),
            
            'KEY_R5C0_PRESSED': lambda: self.launch_spotify(),
            'KEY_R5C1_PRESSED': lambda: print("Key R5C1 pressed"),
            'KEY_R5C2_PRESSED': lambda: print("Key R5C2 pressed"),
            'KEY_R5C3_PRESSED': lambda: print("Key R5C3 pressed"),
            
            # Row 1-4 keys
            'KEY_R1C0_PRESSED': lambda: print("Key R1C0 pressed"),
            'KEY_R1C1_PRESSED': lambda: print("Key R1C1 pressed"),
            'KEY_R1C2_PRESSED': lambda: print("Key R1C2 pressed"),
            'KEY_R1C3_PRESSED': lambda: print("Key R1C3 pressed"),
            'KEY_R1C4_PRESSED': lambda: print("Key R1C4 pressed"),
            # ... add more as needed
        }
        
        # App names for volume control
        self.app_names = {
            'spotify': ['spotify.exe'],
            'discord': ['discord.exe'],
            'game': ['java.exe', 'Valorant.exe', 'RustClient.exe', 'csgo.exe'],  # Add game executables
            'chrome': ['chrome.exe'],
            'firefox': ['firefox.exe'],
        }
    
    def find_device(self):
        """Auto-detect Hexadecipad serial port"""
        ports = serial.tools.list_ports.comports()
        for port in ports:
            # Look for RP2040 or CircuitPython devices
            if 'XIAO' in port.description or 'RP2040' in port.description or 'CircuitPython' in port.description:
                return port.device
        
        # Fallback: use first available COM port
        if ports:
            return ports[0].device
        return None
    
    def connect(self):
        """Connect to the Hexadecipad device"""
        if not self.port:
            self.port = self.find_device()
            if not self.port:
                print("Error: Could not find device. Specify port manually.")
                return False
        
        try:
            print(f"Connecting to {self.port}...")
            self.ser = serial.Serial(self.port, self.baudrate, timeout=1)
            time.sleep(2)  # Wait for connection to stabilize
            print(f"Connected to {self.port}")
            return True
        except Exception as e:
            print(f"Error connecting: {e}")
            return False
    
    def disconnect(self):
        """Disconnect from device"""
        if self.ser:
            self.ser.close()
            print("Disconnected")
    
    def run(self):
        """Main loop - listen for messages and execute actions"""
        if not self.connect():
            return
        
        self.running = True
        print("Listening for commands... (Press Ctrl+C to exit)")
        print("Protocol format: ENC1_UP, ENC1_DOWN, KEY_R1C2_PRESSED, etc.")
        
        try:
            while self.running:
                if self.ser and self.ser.in_waiting:
                    try:
                        message = self.ser.readline().decode('utf-8').strip()
                        if message:
                            self.handle_message(message)
                    except Exception as e:
                        print(f"Error reading: {e}")
                time.sleep(0.01)
        except KeyboardInterrupt:
            print("\nExiting...")
        finally:
            self.disconnect()
    
    def handle_message(self, message):
        """Process incoming message and execute corresponding action"""
        print(f"Received: {message}")
        
        if message in self.action_map:
            try:
                self.action_map[message]()
            except Exception as e:
                print(f"Error executing action: {e}")
        elif message == "DEVICE_READY":
            print("Device initialized")
        else:
            print(f"Unknown command: {message}")
    
    def get_app_volume(self, app_name):
        """Get audio session for specific app"""
        app_names = self.app_names.get(app_name.lower(), [app_name])
        sessions = AudioUtilities.GetAllSessions()
        
        for session in sessions:
            if session.Process:
                exe_name = os.path.basename(session.Process.name()).lower()
                if any(name.lower() in exe_name for name in app_names):
                    return session.SimpleAudioVolume
        return None
    
    def change_app_volume(self, app_name, delta):
        """Change volume for specific app"""
        volume = self.get_app_volume(app_name)
        if volume:
            try:
                current = volume.GetMasterVolume()
                new_volume = max(0.0, min(1.0, current + delta))
                volume.SetMasterVolume(new_volume, None)
                pct = int(new_volume * 100)
                print(f"{app_name}: {pct}%")
            except Exception as e:
                print(f"Error changing volume: {e}")
        else:
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

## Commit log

2026-01-02 Add everything
    [HexadecipadV2.kicad_pcb, HexadecipadV2.kicad_sch]
2026-01-05 Fix all traces
    I stopped using freerouting because i realised it was not allowed and it was a huge pain. redid all the traces by hand and made some power planes. removed all of my LEDs because 1.21 GIGAWATTS
    [HexadecipadV2.kicad_pcb, HexadecipadV2.kicad_sch, freerouting.dsn]
2026-01-09 make the case
    took me 5 million years just to make this thing and it doesnt even look good
    [Case-Production.step, Case-Production.x_t, Encoder.STEP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]
2026-01-23 added all my files after too long of not commiting
    [Case bottom.stl, Case top.stl, Case-Production.step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]
2026-01-23 Added screws
2026-01-23 Update link to Interactive BOM in README.md
2026-01-27 Add production-ready files and documentation for CAD, firmware, and PCB
2026-02-22 add screenshots of pcb prices
